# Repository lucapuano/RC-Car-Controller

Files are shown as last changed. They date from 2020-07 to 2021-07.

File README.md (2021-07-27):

# RC Car Controller
The project consist of a simple RC car controller based on the popular STM32F103C8T6, programmable through the usb port by the FT232RL.
There are two connector, one for the servo motor and the other for the ESC.  
The whole circuit is powered by the ESC connector.
Current version: V2
## PCB Screenshots
### Layers view
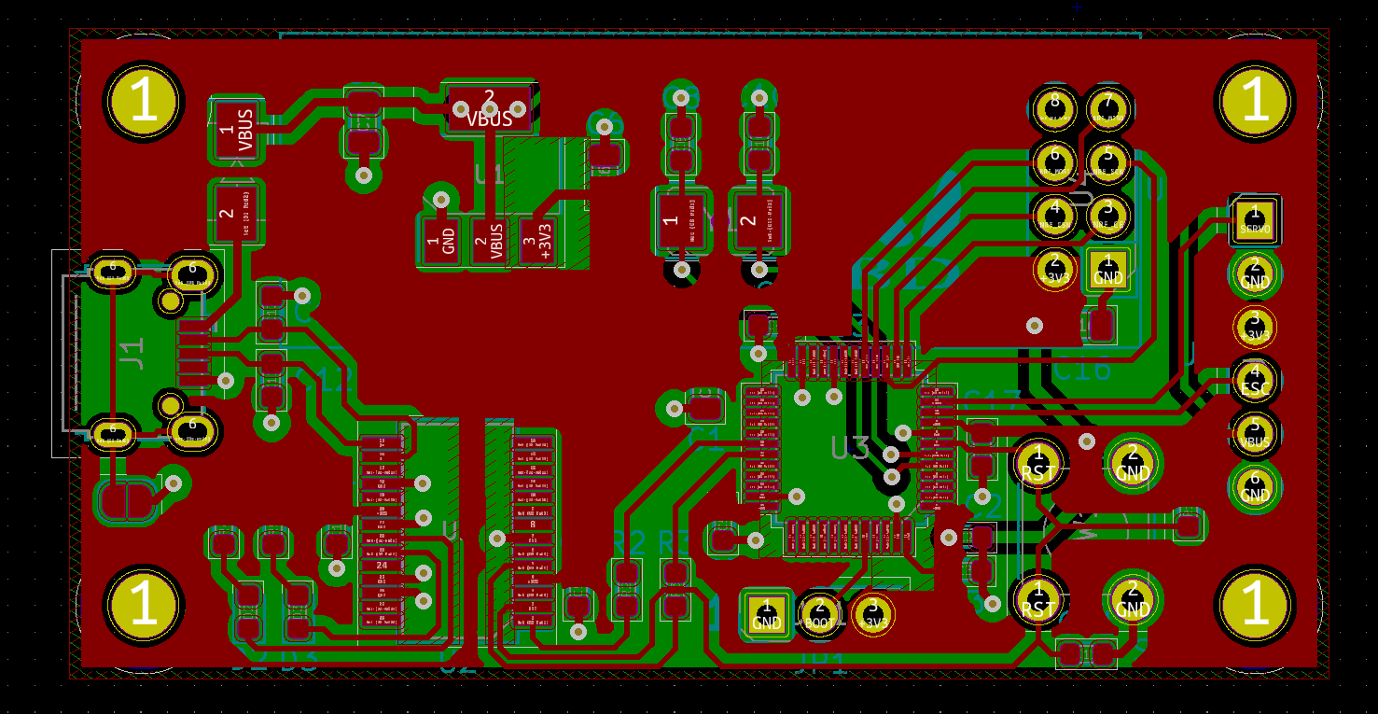
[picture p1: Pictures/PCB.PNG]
bla

### 3D view
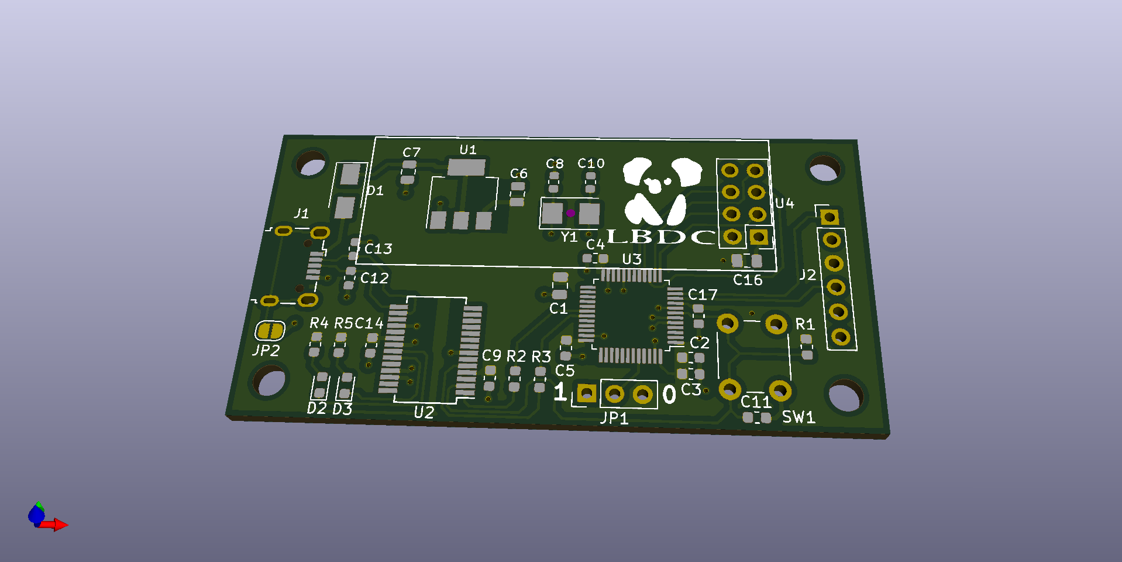
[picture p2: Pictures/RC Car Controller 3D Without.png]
lol

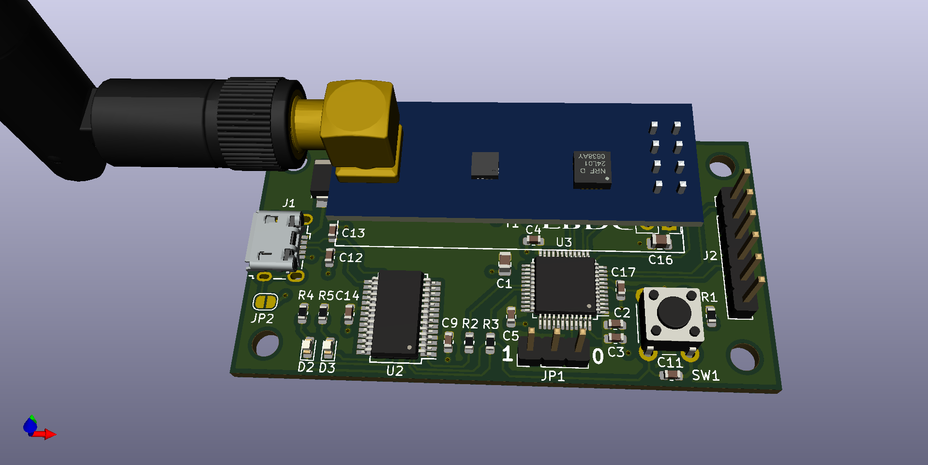
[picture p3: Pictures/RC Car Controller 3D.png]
lol2

## UPDATES
- Improved the design and traces
- Solved some issues and errors in design

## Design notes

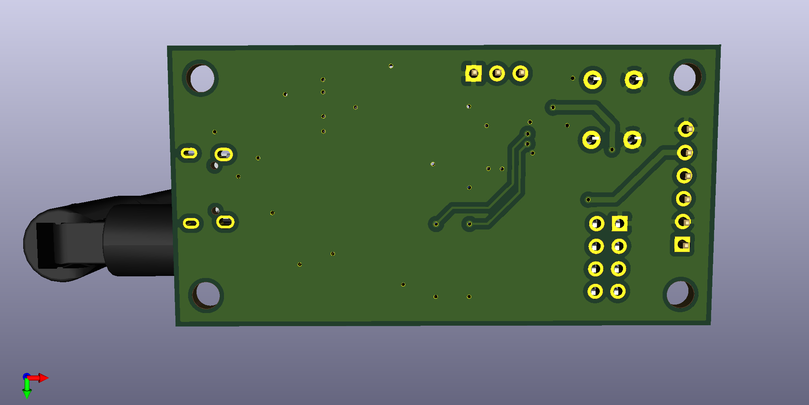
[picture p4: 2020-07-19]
Pictures/RC Car Controller 3D 2.png

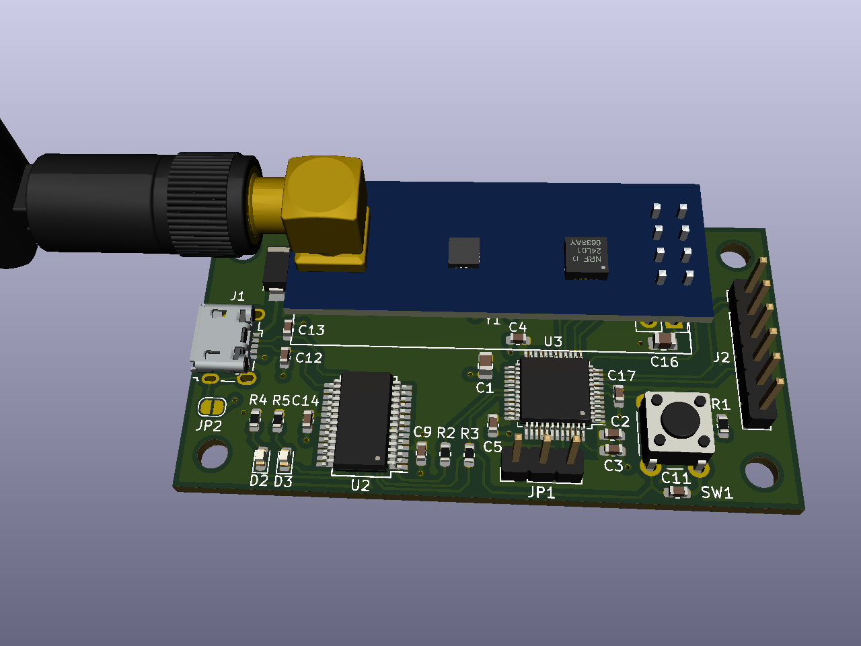
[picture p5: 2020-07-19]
Pictures/RC Car Controller 3D 4_3.png

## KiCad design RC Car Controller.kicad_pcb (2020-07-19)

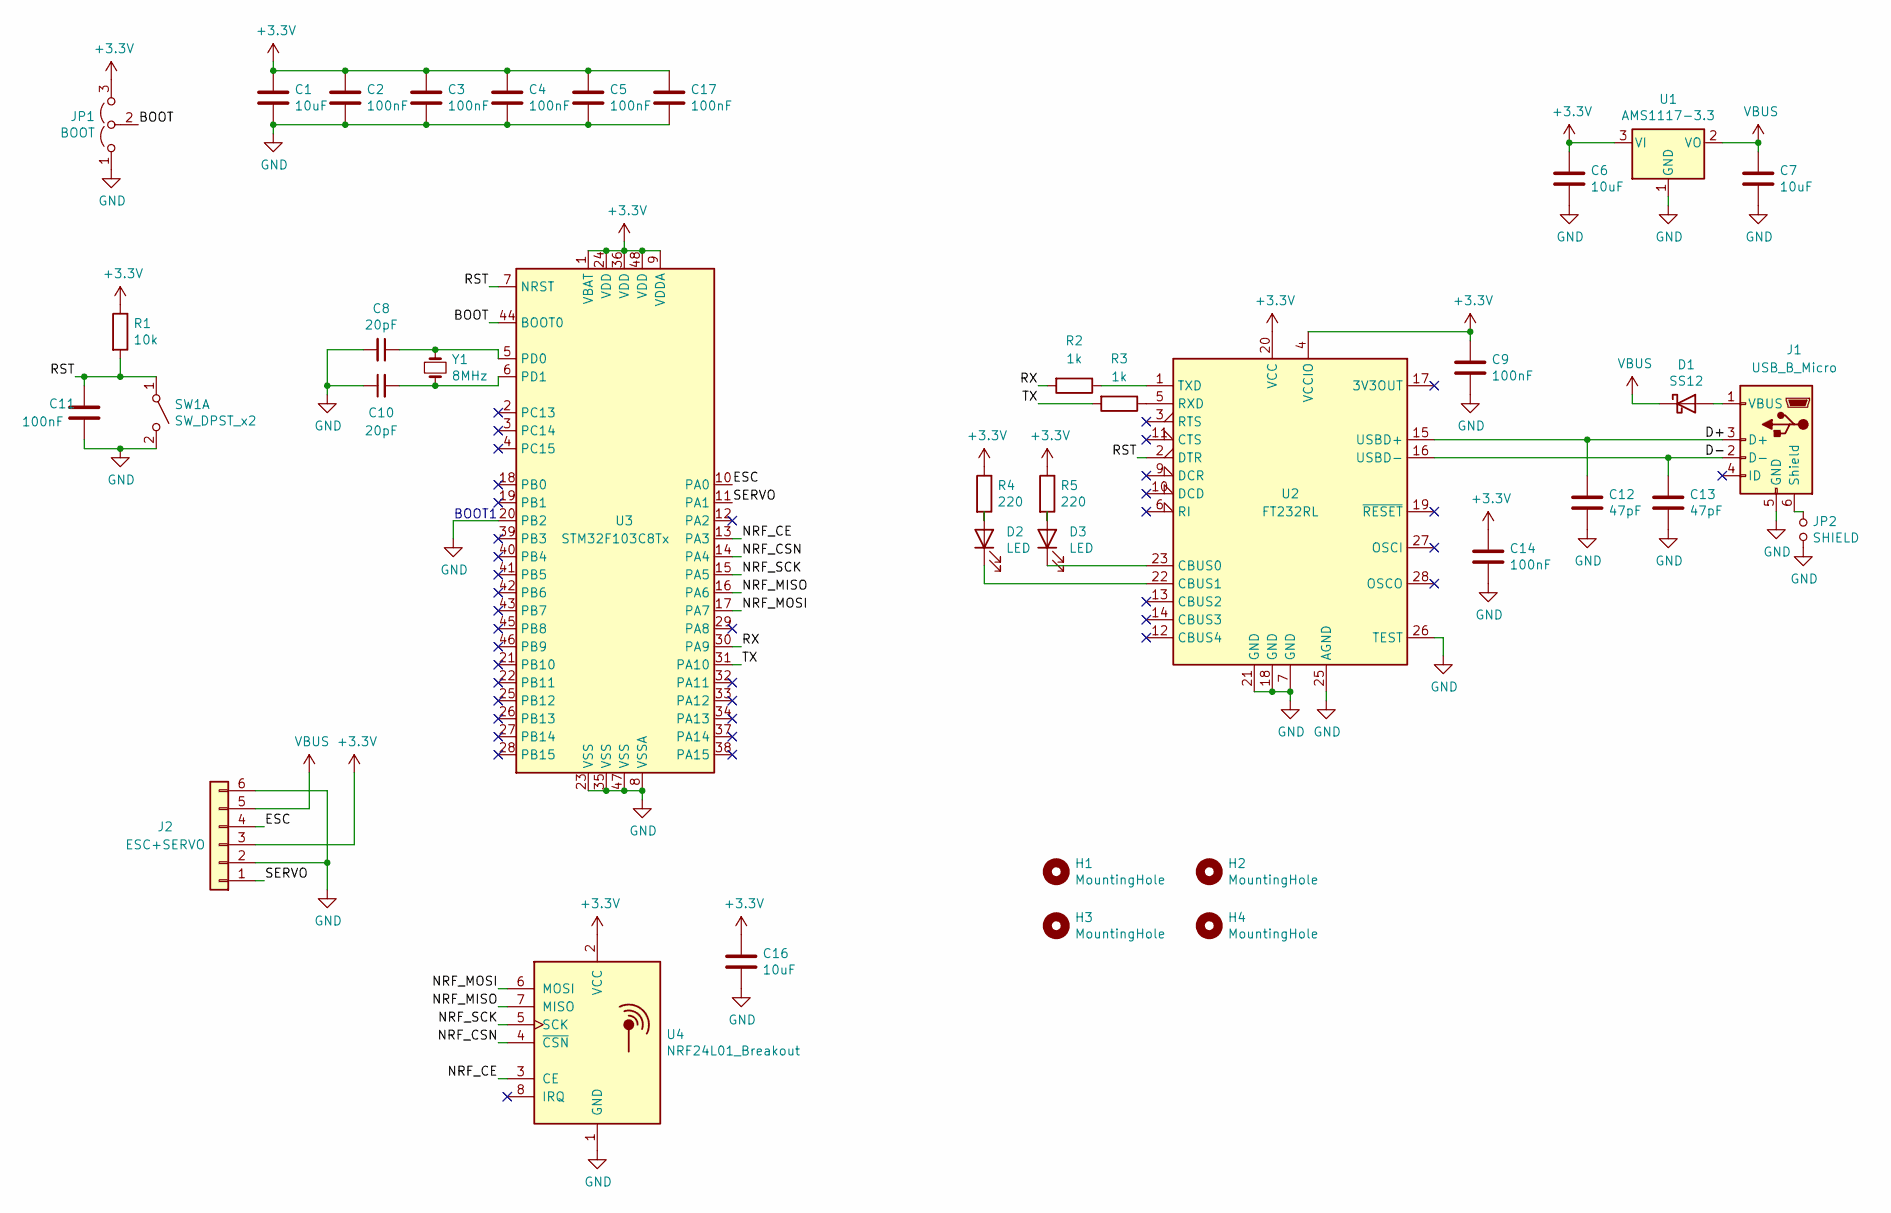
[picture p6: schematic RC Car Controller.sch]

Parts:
C1, C6, C7, C16: 10uF; C_0805_2012Metric
C2, C3, C4, C5, C9, C11, C14, C17: 100nF; C_0603_1608Metric
C8, C10: 20pF; C_0603_1608Metric
C12, C13: 47pF; C_0603_1608Metric
D1: SS12; D_SMA
D2, D3: LED; LED_0603_1608Metric
H1, H2, H3, H4: MountingHole; MountingHole_3mm
J1: USB_B_Micro; USB_Micro-B_Wuerth_629105150521
J2: ESC+SERVO; PinHeader_1x06_P2.54mm_Vertical
JP1: BOOT; PinHeader_1x03_P2.54mm_Vertical
JP2: SHIELD; SolderJumper-2_P1.3mm_Open_RoundedPad1.0x1.5mm
R1: 10k; R_0603_1608Metric
R2, R3: 1k; R_0603_1608Metric
R4, R5: 220; R_0603_1608Metric
SW1: SW_DPST_x2; SW_PUSH_6mm
U1: AMS1117-3.3; SOT-223-3_TabPin2
U2: FT232RL; SSOP-28_5.3x10.2mm_P0.65mm
U3: STM32F103C8Tx; LQFP-48_7x7mm_P0.5mm
U4: NRF24L01_Breakout; NRF24L01 LA PNA
Y1: 8MHz; Crystal_SMD_5032-2Pin_5.0x3.2mm

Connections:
+3V3: C1.1, C2.1, C3.1, C4.1, C5.1, C6.1, C9.1, C14.1, C16.1, C17.1, J2.3, JP1.3 (B), R1.1, R4.1, R5.1, U1.3 (VI), U2.4 (VCCIO), U2.20 (VCC), U3.1 (VBAT), U3.9 (VDDA), U3.24 (VDD), U3.36 (VDD), U3.48 (VDD), U4.2 (VCC)
/BOOT: JP1.2 (C), U3.44 (BOOT0)
/D+: C12.1, J1.3 (D+), U2.15 (USBD+)
/D-: C13.1, J1.2 (D-), U2.16 (USBD-)
/ESC: J2.4, U3.10 (PA0)
/NRF_CE: U3.13 (PA3), U4.3 (CE)
/NRF_CSN: U3.14 (PA4), U4.4 (~CSN)
/NRF_MISO: U3.16 (PA6), U4.7 (MISO)
/NRF_MOSI: U3.17 (PA7), U4.6 (MOSI)
/NRF_SCK: U3.15 (PA5), U4.5 (SCK)
/RST: C11.1, R1.2, SW1.1 (A), U2.2 (DTR), U3.7 (NRST)
/RX: R2.2, U3.30 (PA9)
/SERVO: J2.1, U3.11 (PA1)
/TX: R3.2, U3.31 (PA10)
GND: C1.2, C2.2, C3.2, C4.2, C5.2, C6.2, C7.2, C8.2, C9.2, C10.1, C11.2, C12.2, C13.2, C14.2, C16.2, C17.2, J1.5 (GND), J2.2, J2.6, JP1.1 (A), JP2.2, SW1.2 (B), U1.1 (GND), U2.7 (GND), U2.18 (GND), U2.21 (GND), U2.25 (AGND), U2.26 (TEST), U3.8 (VSSA), U3.20 (PB2), U3.23 (VSS), U3.35 (VSS), U3.47 (VSS), U4.1 (GND)
unnamed: C8.1, U3.5 (PD0), Y1.1
unnamed: C10.2, U3.6 (PD1), Y1.2
unnamed: D1.2 (A), J1.1 (VBUS)
unnamed: D2.1 (K), U2.22 (CBUS1)
unnamed: D2.2 (A), R4.2
unnamed: D3.1 (K), U2.23 (CBUS0)
unnamed: D3.2 (A), R5.2
unnamed: J1.6 (Shield), JP2.1
unnamed: R2.1, U2.1 (TXD)
unnamed: R3.1, U2.5 (RXD)
VBUS: C7.1, D1.1 (K), J2.5, U1.2 (VO)

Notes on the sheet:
BOOT1

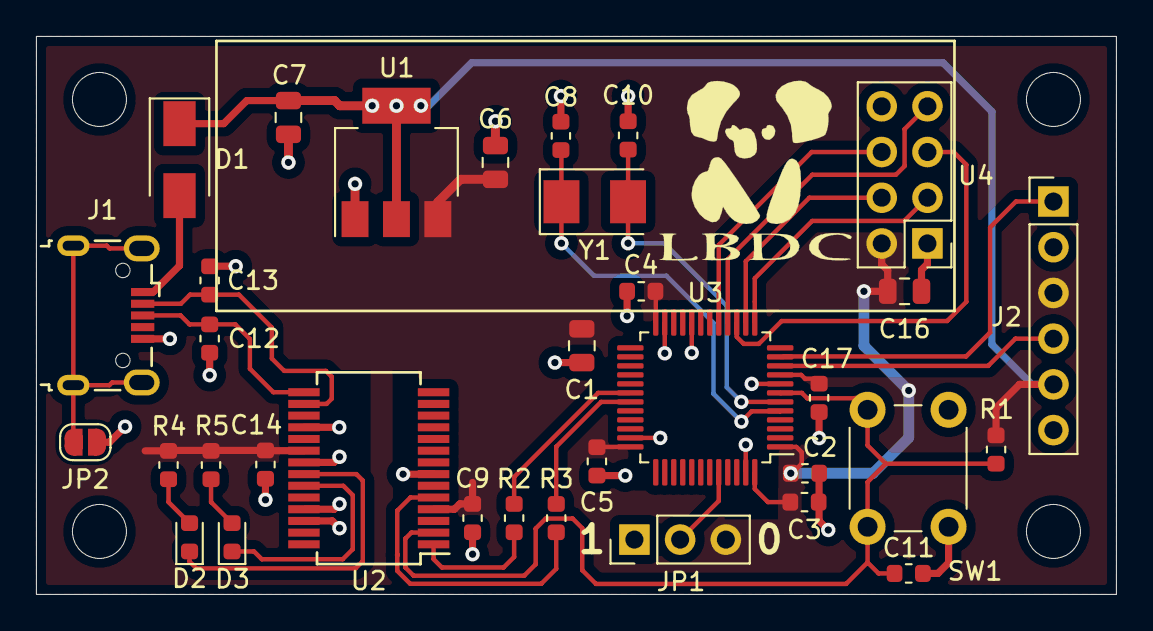
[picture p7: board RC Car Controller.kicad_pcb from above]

Board: 2 copper layers, 60.0 x 31.0 mm, 38 parts (0 on the bottom side), 26 nets.
